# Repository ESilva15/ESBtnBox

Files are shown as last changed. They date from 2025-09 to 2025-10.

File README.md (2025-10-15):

# ESBtnBox
Simple button box for simracing and other activities. This works but its still
an early phase and I hope to subject it to a great list of improvements from
polishing the 3D models to making the whole thing more compact.

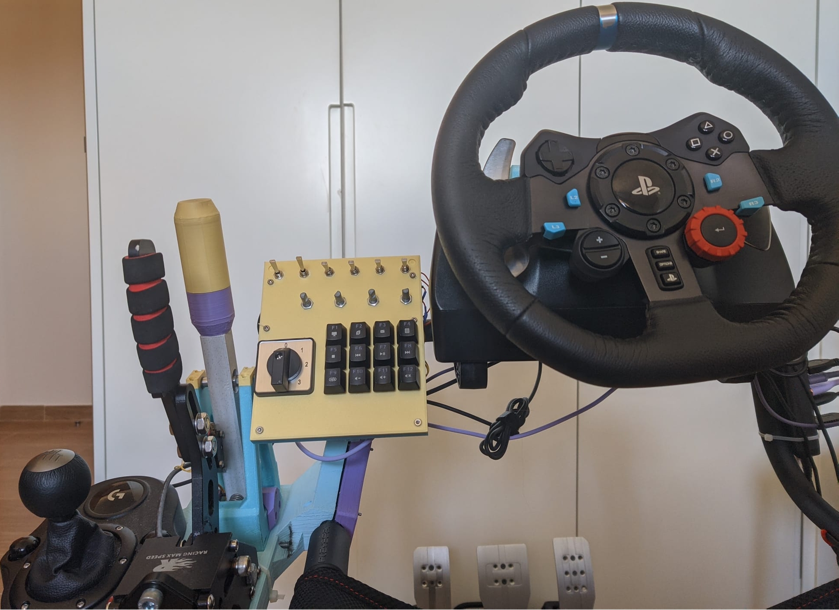
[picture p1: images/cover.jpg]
Project Overview


# Components
## Electronics
| Part | Quantity |
| --- | --- |
| Arduino Pro Micro (ATmega32u4) | 1 |
| Female Headers for pro micro | 24 |
| JST-PH Connectors (6 pin) male and female | 1 | [^1]
| JST-PH Connectors (5 pin) male and female | 1 |
| JST-PH Connectors (3 pin) male and female | 1 |
| JST-PH Connectors (2 pin) male and female | 3 |
| Perf boards 70mm x 500mm | 2 |
| 100nF Capacitors | 10 |
| 74HC595N Shift Register | 1 |
| 74HC165N Shift Register | 1 |
| 10k Ohm Resistors | 20 |
| 1N4148 diodes | 26 |
| Toggle Switches | 6 | [^2]
| Rotary Encoders | 4 |
| 2P LW26-25 series changeover switch | 1 |
| MX switches (and keycaps I recon) | 12 |
| Wiring and consumables | Lots |

[^1]: I used 2mm pitch for these connectors, but they didn't really match the
pitch of the perf board I was using. Choosing other pitches wouldn't be a bad
idea.

[^2]: I used 4 On-Off-On switches and 2 MOM-Off-MOM switches. Permutate it
however you desire.

## Hardware
| Part | Quantity |
| --- | --- |
| M3 nuts | 20 | [^3]
| M5 nuts | 2 |
| M3x40mm | 4 | [^4]
| M3x12mm | 2 |
| M3x50mm | 4 |
| M5x20mm | 2 |
| M3 t-nut | 2 |
| M2 Heat Inserts | 7 |
| M2x6mm | 7 |

[^3]: 4 of these are optional: the ones on the outwards facing piece that connects 
to the playseat and the 2 top ones on the front plate

[^4]: 2 of these are optional: the ones on the outwards facing piece that connects
to the playseat structure.

## 3D printed parts
- Clamp: composed by the files `./3DModel/seatAttachement_screwSide.FCStd` and
`./3DModel/seatAttachement.FCStd`, the latter is the the one facing the seating
user and the first the one facing outwards
- Arm which is the file `./3DModel/arm.FCStd`
- T-slot which bolts to the front plate: `./3DModel/tSlot.FCStd`
- T-slot bracket which bolts to the t-slot and the arm: `./3DModel/tSlotAttachement.FCStd`
- Front plate where all the buttons are mounted to: `./3DModel/frontPlate.FCStd`
- Cover plate which where the "pcb" mounts and connects to the front plate: `./3DModel/pcbHolder.FCStd`
- Very simple knob for the rotary encoders: `./3DModel/knob.FCStd`

# Assembly
The assembly is straightforward, specially if you are the one that imagined it:
1. put the toggle switches into their through holes and bolt them
2. put the rotary encoders into their through holes and bolt them
3. insert the MX switches into their holes
4. bolt the changeover switch into its slot
5. wire the things according to the schematic. I started by doing the columns
and then the rows and left the rotary part of the encoders for the end. Crimp
the JSH-PH connectors on the rows, columns and rotary encoders
6. solder the components to the perf boards. I joined the 2 perf boards like the
images show
7. mount the back cover
    1. put the heat inserts into the back cover
    2. bolt the perf boards to the back cover
    3. drill holes on the front plate for the back cover holes. They go 7.5mm
    in from the front plate edges, 1.5mm below the toggle switches and are spaced
    apart by 45mm
    4. pass the M3x50mm bolts trough the front plate and put nuts holding them
    5. place nuts 8mm down from the tip on them
    6. connect the front plate electronics to the pcb
    7. place the back cover on the M3x50mm bolts and put nuts on it
8. bolt the t-slot 3D printed part tot he front plate and pass the t-nuts into it
9. place the t-slot attachement on the t-nuts. Leave them loose for later adjustments
10. heat insert the M5 nuts into the arm and the M3 nuts on inside part of the clamp
11. loosely assemble the arm
12. place the assembly on the playseat and clamp it down with the M3x40mm bolts
13. do the final adjustments and tighten everything down

## Schematics
Well, I'm not very well versed on KiCAD or eletronics design in general, so all
I have is the following hand drawings and pinouts. I will make something better 
at some point.

### Shift registers:
| Pro Micro Pin | 74HC595N Pin |
| --- | --- |
| 4 | 14 |
| 5 | 12 |
| 6 | 11 |
| GND | 8 |
| GND | 13 |
| 5V | 16 |
| 5V | 10 |
Put a capacitor on the 5V and common Ground

| Pro Micro Pin | 74HC165N Pin |
| --- | --- |
| 7 | 15 |
| 8 | 7 |
| 9 | 2 |
| 10 | 1 |
| GND | 8 |
| GND | 13 |
| 5V | 16 |
Put a capacitor on the 5V and common Ground

#### Shift registers to kbd matrix
Rows on the 595N:
| 74HC595N Pin | Matrix Row |
| --- | --- |
| 1 | 5 |
| 2 | 4 |
| 3 | 3 |
| 4 | 2 |
| 5 | 1 |
| 6 | 0 |

Columns on the 165N:
| 74HC165N Pin | Matrix Col |
| --- | --- |
| 14 | 4 |
| 3 | 3 |
| 4 | 2 |
| 5 | 1 |
| 6 | 0 |

### Rotary Encoders
Referring to the rotary encoders from the front view.
Only the first one will have the common ground specified because thats the one
that runs the ground for all the others.

1st:
| Pro Micro Pin | Rotary Encoder Pin |
| --- | --- |
| 14 | Top |
| GND | Middle |
| 16 | Bottom |

2nd:
| Pro Micro Pin | Rotary Encoder Pin |
| --- | --- |
| 15 | Top |
| 18 | Bottom |

3rd:
| Pro Micro Pin | Rotary Encoder Pin |
| --- | --- |
| 19 | Top |
| 20 | Bottom |

4th:
| Pro Micro Pin | Rotary Encoder Pin |
| --- | --- |
| 3 | Top |
| 2 | Bottom |

### Visual Aid
Matrix Wiring:
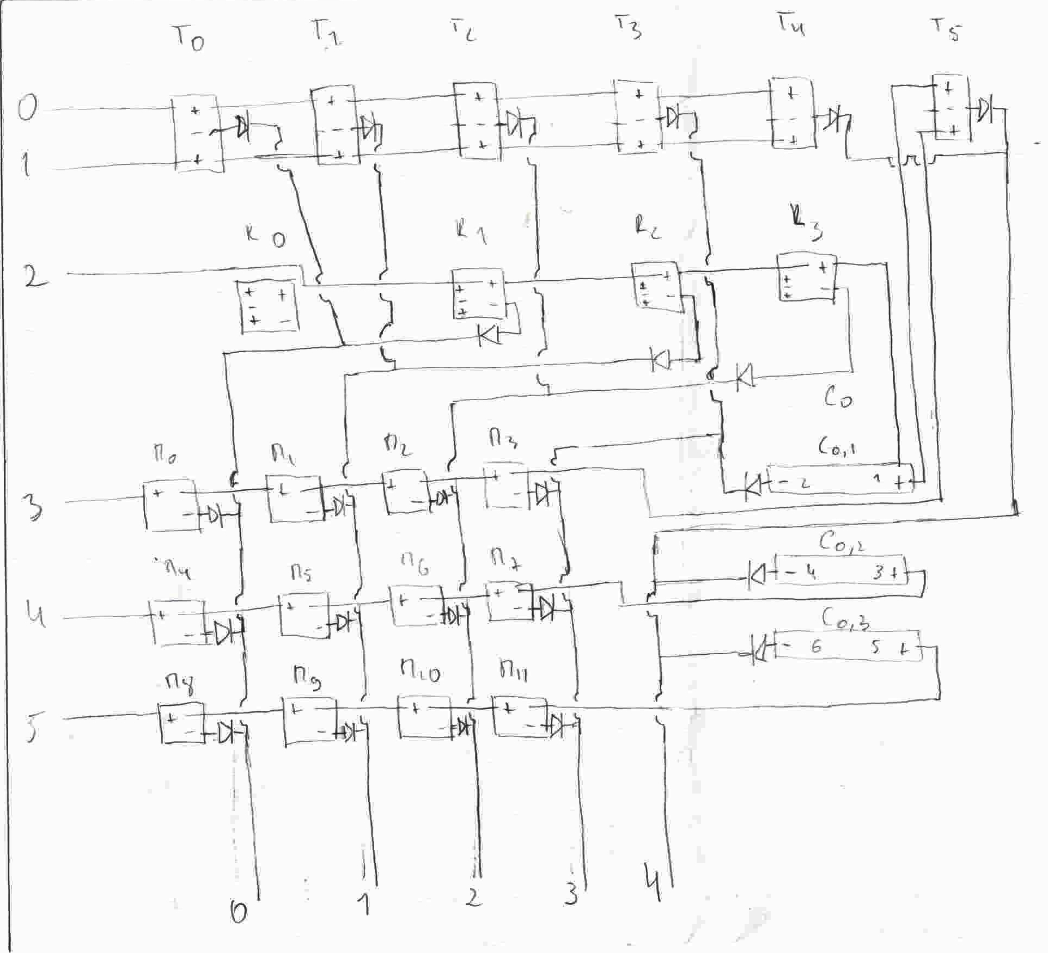
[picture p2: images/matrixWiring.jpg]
Matrix Wiring Schematic

    
2 Pin JST-PH connectors from the rotary encoder:
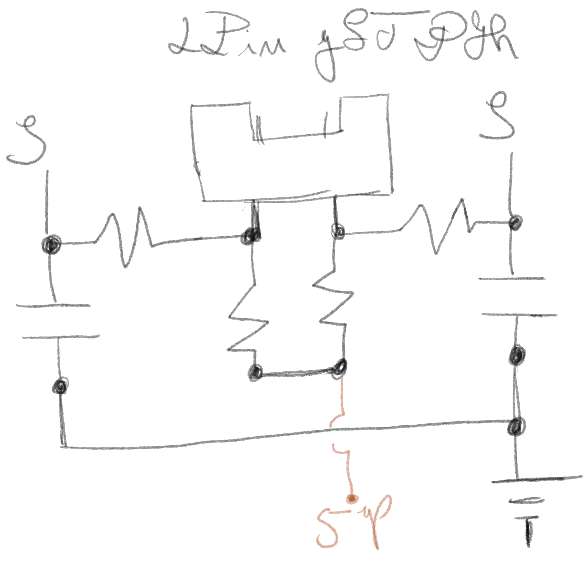
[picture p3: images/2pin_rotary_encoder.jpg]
2 Pin JST-PH connectors from the rotary encoder


3 Pin JST-PH connectors from the rotary encoder:
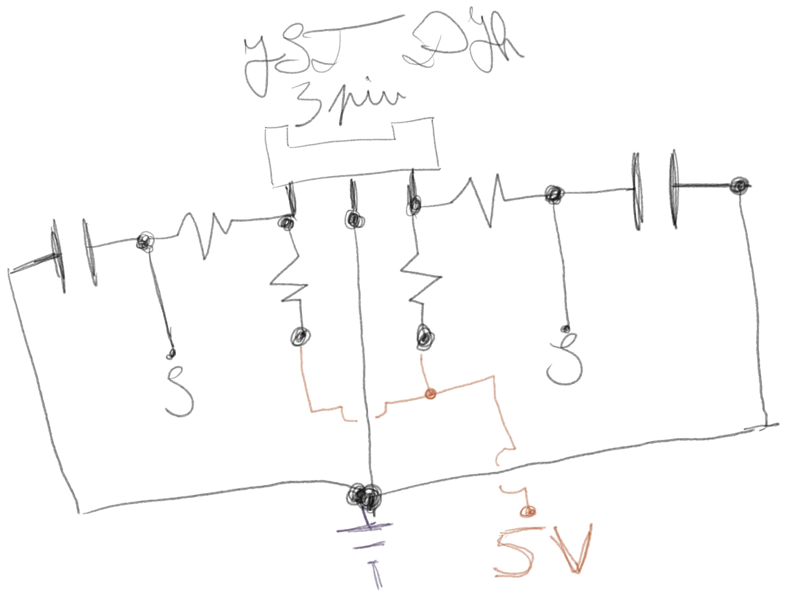
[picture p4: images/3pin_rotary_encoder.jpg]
3 Pin JST-PH connectors from the rotary encoder


## Assembled project
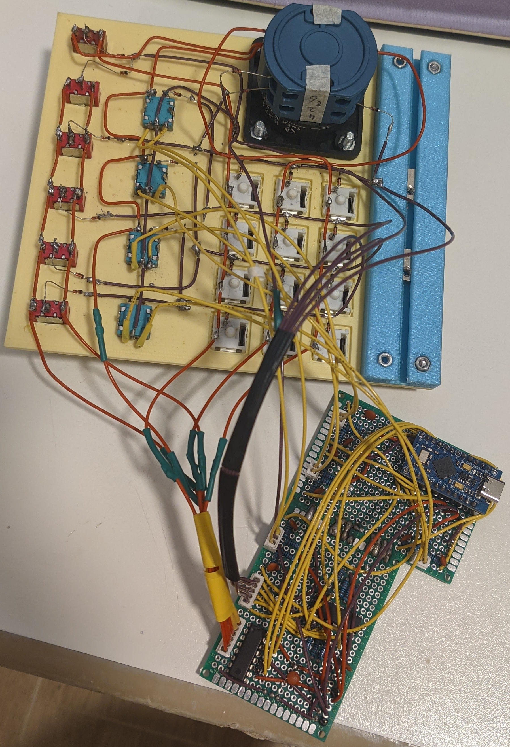
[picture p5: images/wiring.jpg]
Wiring

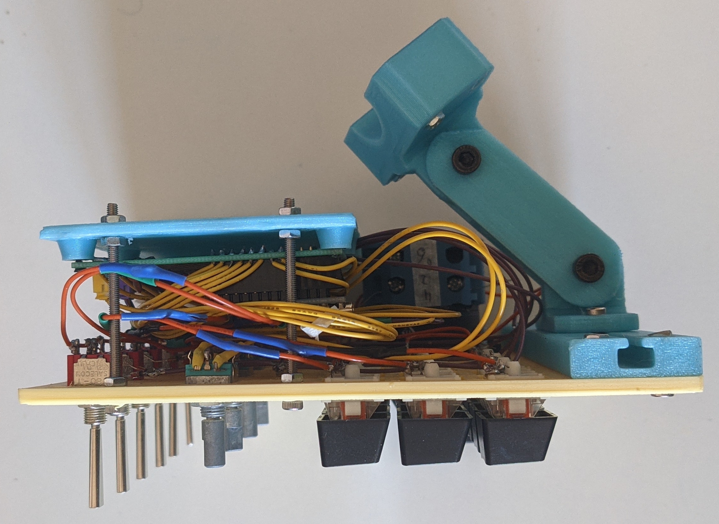
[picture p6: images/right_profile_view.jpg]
Right Profile View

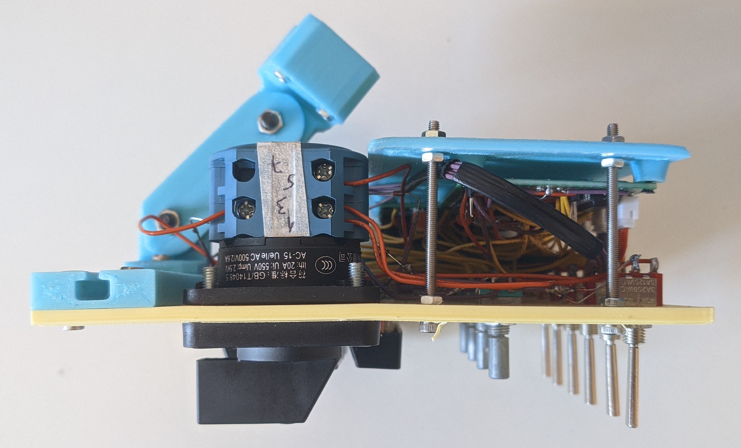
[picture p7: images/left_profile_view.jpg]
Left Profile View

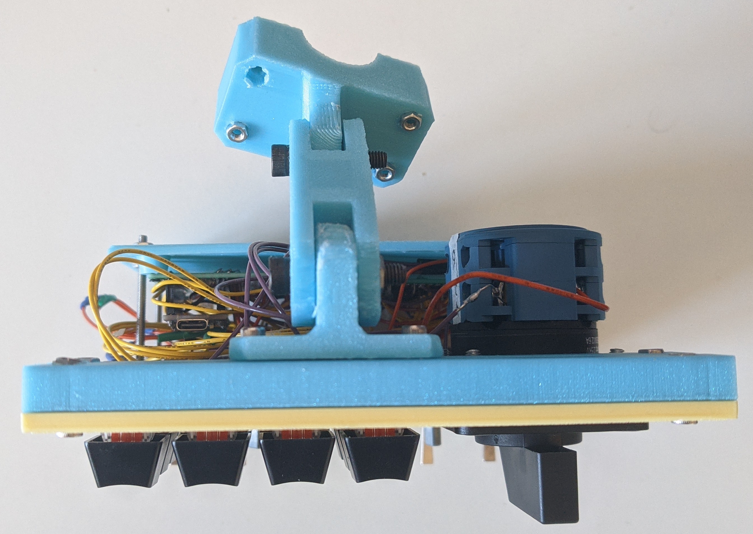
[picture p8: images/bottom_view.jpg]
Bottom View

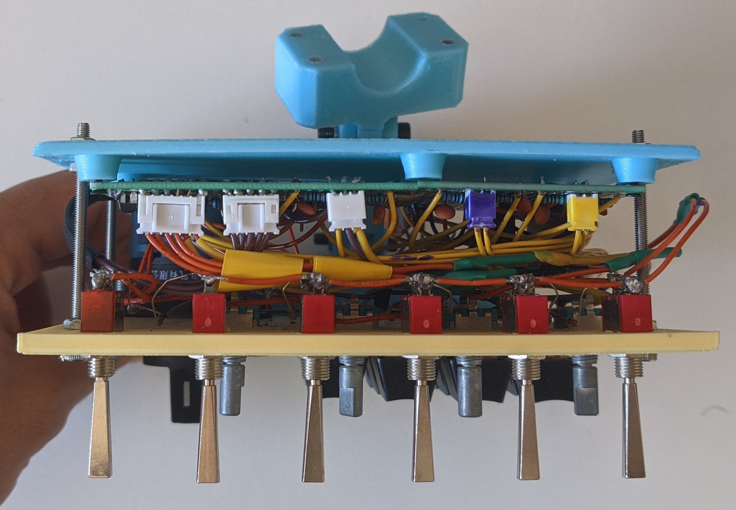
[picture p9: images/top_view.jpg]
Top View

Fully Assembled

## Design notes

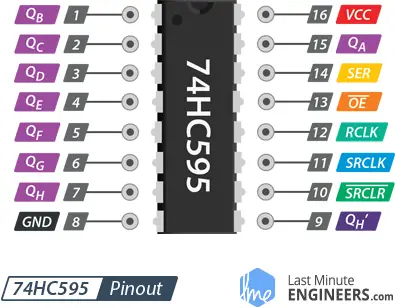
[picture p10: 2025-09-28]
images/595n_pinout.webp

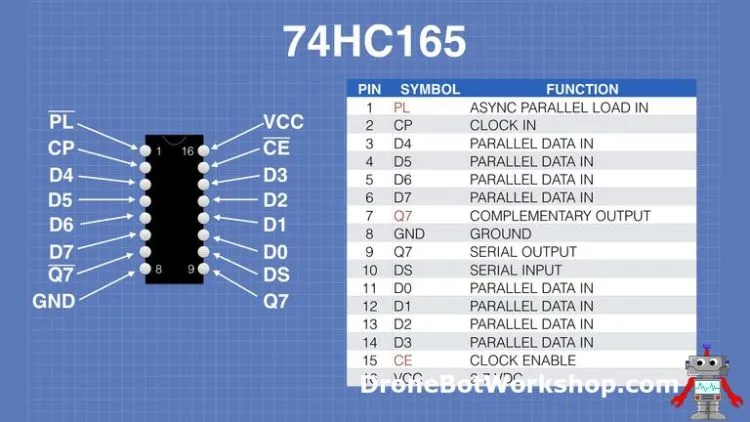
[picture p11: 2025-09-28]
images/165_pinout.webp

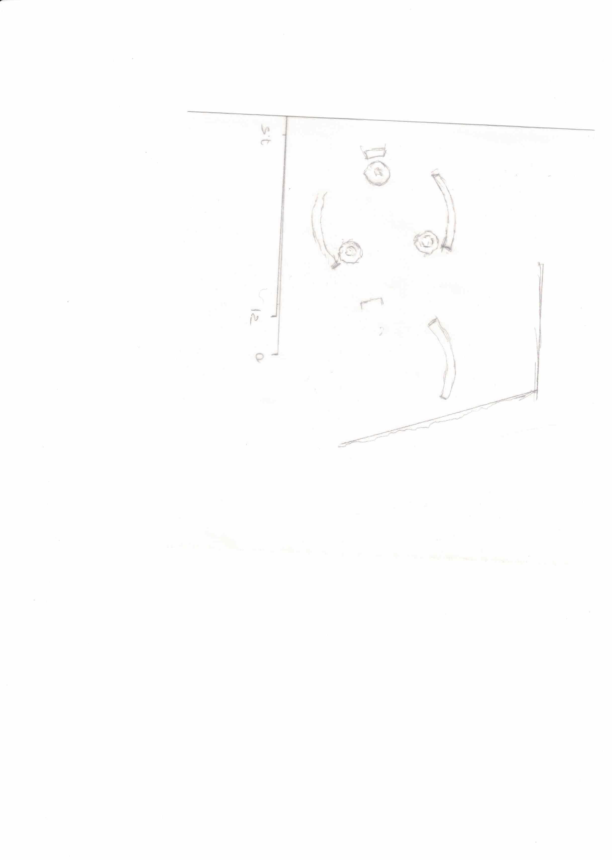
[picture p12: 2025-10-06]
3DModel/playseatBracketAngle.jpg

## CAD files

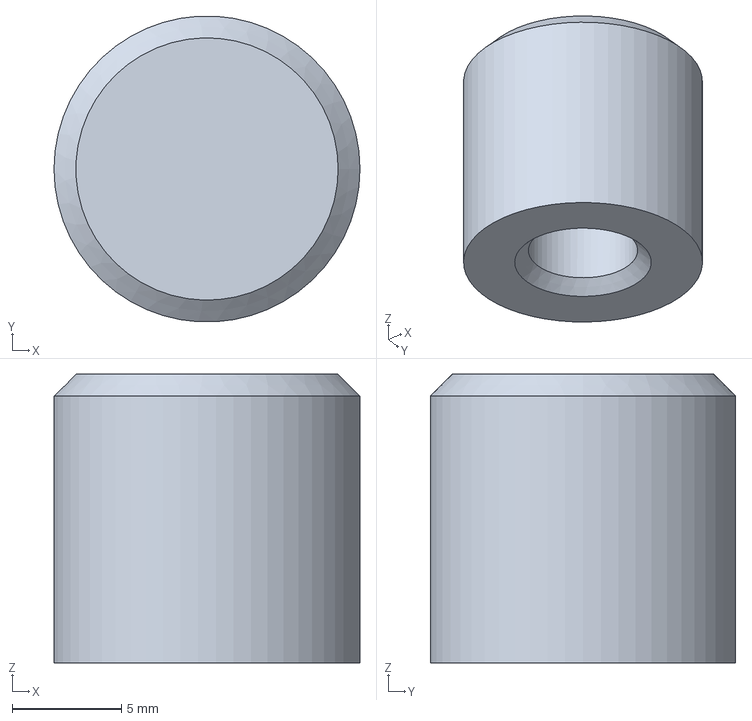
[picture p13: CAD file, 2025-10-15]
3DModel/knob.FCStd
14.0 x 14.0 x 13.2 mm

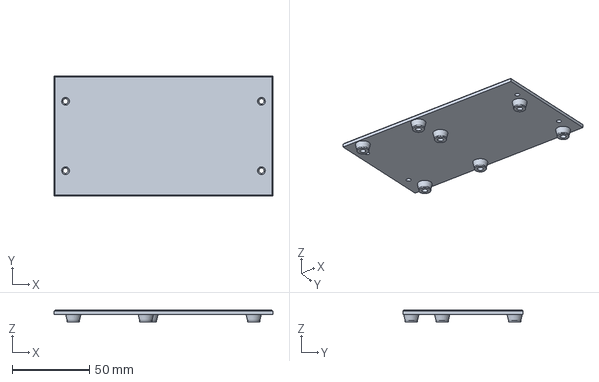
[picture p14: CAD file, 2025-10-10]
3DModel/pcbHolder.FCStd
142.0 x 78.0 x 8.00 mm

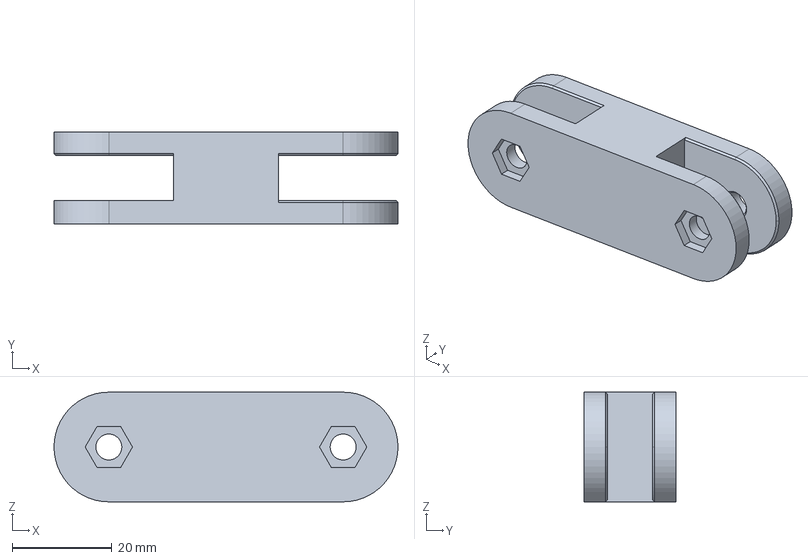
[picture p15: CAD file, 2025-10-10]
3DModel/extension.FCStd
69.0 x 18.4 x 22.0 mm

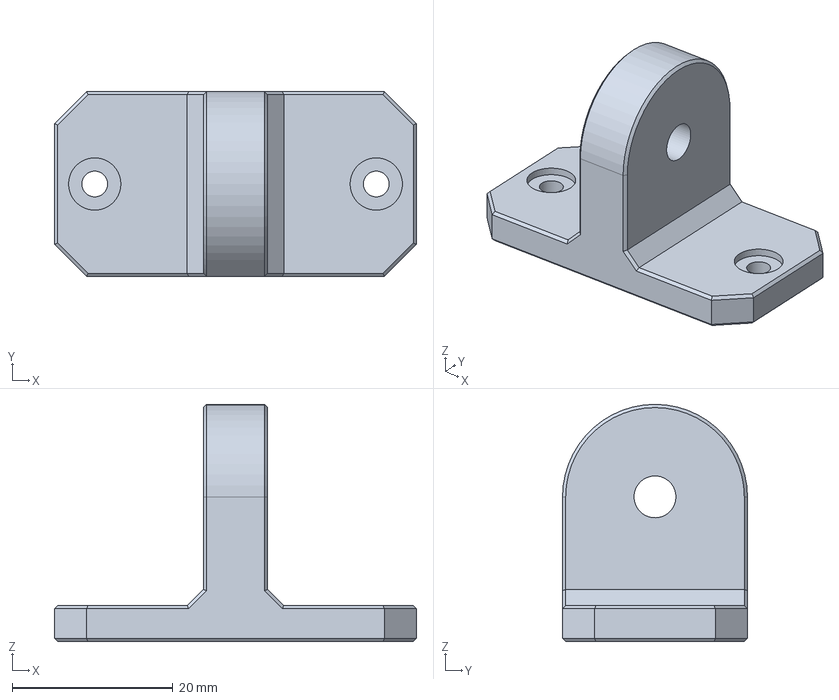
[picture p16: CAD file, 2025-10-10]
3DModel/tSlotAttachement.FCStd
45.0 x 23.0 x 29.5 mm

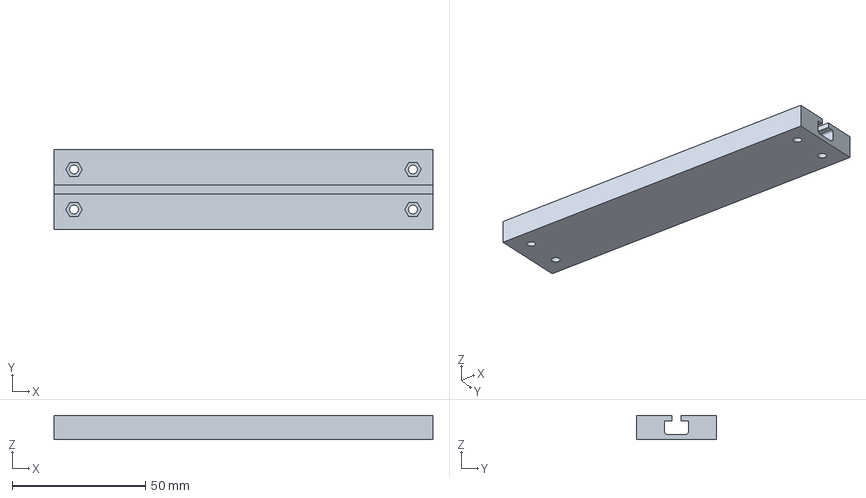
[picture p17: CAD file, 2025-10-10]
3DModel/tSlot.FCStd
142.0 x 30.0 x 9.00 mm

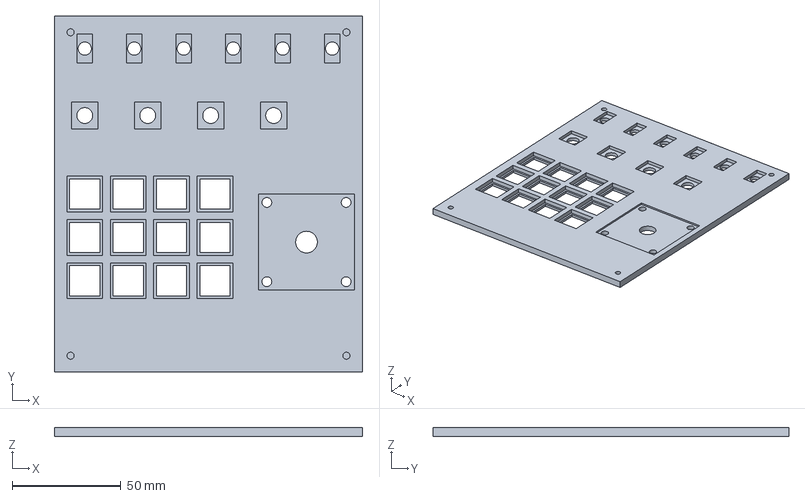
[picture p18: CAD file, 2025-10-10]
3DModel/frontPlate.FCStd
142.0 x 164.0 x 4.00 mm

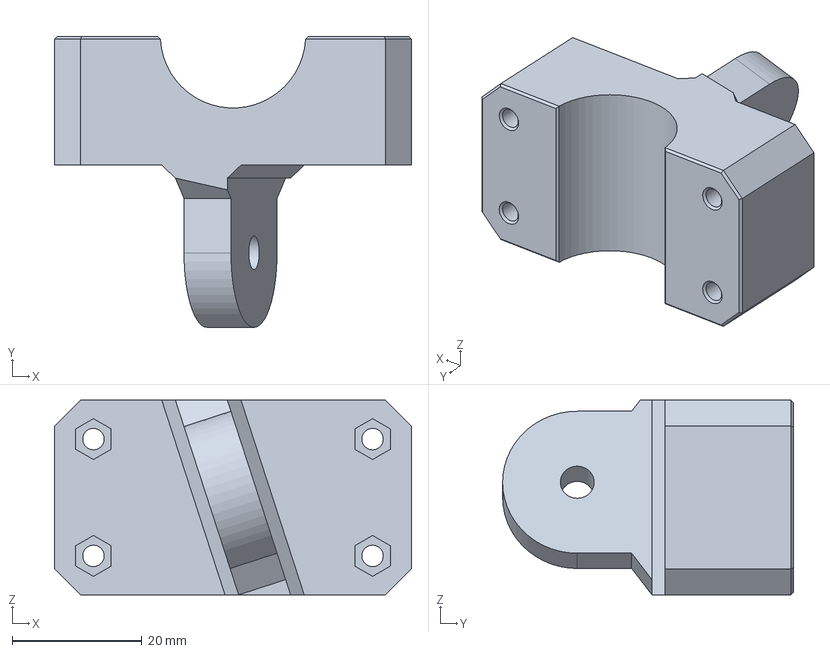
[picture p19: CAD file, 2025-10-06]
3DModel/seatAttachement.FCStd
55.0 x 44.8 x 30.0 mm

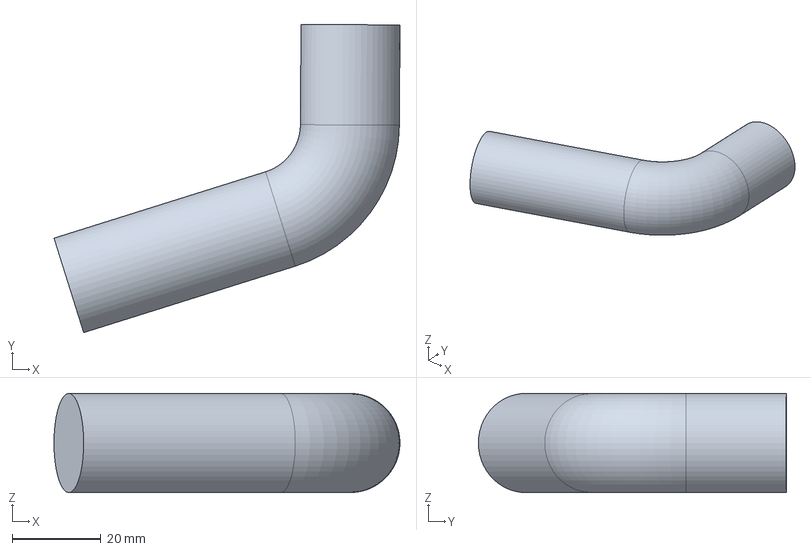
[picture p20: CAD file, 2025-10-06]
3DModel/arm.FCStd
78.0 x 69.5 x 22.3 mm

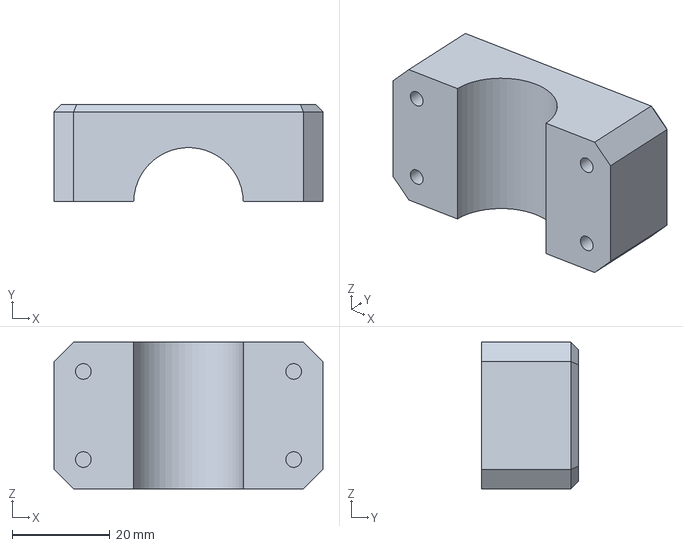
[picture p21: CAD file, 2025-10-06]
3DModel/seatAttachement_screwSide.FCStd
55.0 x 19.8 x 30.0 mm

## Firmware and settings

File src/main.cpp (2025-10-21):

/* BtnBOX by Eduardo Silva
 * Notes:
 * calling Wire.begin() will take use of the pins 2 and 3. Maybe try not using
 * them from the getgo
 */

// The Matrix
/* 
 * 1 1 1 R3 F9 F10 F11 F12
 * 1 1 1 R2 F5 F6  F7  F8
 * 1 1 1 M1 F1 F2  F3  F4
 * 1 1 1 m1 R1 r1  r2  r3
 * 1 1 1 M2 T3 T4  T5  T6
 * 1 1 1 m2 t3 t4  t5  t6
 *
 * Toggle Switches (On - Off - On):
 * T -> up, t -> down.
 * From left to right
 *
 * Toggle Switches (Hold On - Off - Hold On)
 * M -> up, m -> down
 * From left to right
 *
 * Puny Rotary Encoders Click:
 * R1 - 3
 * From left to right
 *
 * Chonky Rotary Encoder:
 * R0 - 3
 * Positions on the encoder
 *
 * F keys:
 * F1 - F12
 * Count them
 *
 */

#include <Arduino.h>
#include "595n.h"
#include "165.h"
#include "rotaryEncoder.h"
#include <Joystick.h>

// NOTES - 595N
// On the board, the first output pin on the SR595 is Qb
// Which means that our outputs go from 0b00000010 to 0b01111110
#define IN_SERIAL_PIN 4 // SER   - pin14 (Serial Pin)
#define IN_LATCH_PIN  5 // RCLK  - pin12 (Latch Pin)
#define IN_CLOCK_PIN  6 // SRCLK - pin11 (Clock Pin)
/*                      
+--             --+
|P0 P1 P2 P3 P4 P5|
+-----------------+
*/
#define IN_P0 0b01000000
#define IN_P1 0b00100000
#define IN_P2 0b00010000
#define IN_P3 0b00001000
#define IN_P4 0b00000100
#define IN_P5 0b00000010
uint8_t rows[] = {IN_P0, IN_P1, IN_P2, IN_P3, IN_P4, IN_P5};
const size_t NUM_ROWS = 6;

// NOTES - 165
#define OUT_PARALLEL_LOAD_IN  10 // PL - pin1  (Async Parallel Load In)
#define OUT_CLOCK_IN          9  // CP - pin2  (Clock In)
#define OUT_COMPLEMENTARY_OUT 8  // Q7 - pin7  (Complementary Output)
#define OUT_CLOCK_ENABLE      7  // CE - pin15 (Clock Enable)
/*
+--          --+
|P4 P3 P2 P1 P0|
+--------------+
*/
#define OUT_P0 0b11111110
#define OUT_P1 0b11111101
#define OUT_P2 0b11111011
#define OUT_P3 0b11110111
#define OUT_P4 0b11101111
uint8_t cols[] = {OUT_P0, OUT_P1, OUT_P2, OUT_P3, OUT_P4};
const size_t NUM_COLS = 5;

// Define the matrix state. Its all HIGH because of it being INPUT_PULLUP
// This is the matrix we will use to send the things to the JoyScick library
const unsigned long debounceDelay = 20;
uint8_t lastReading[NUM_ROWS][NUM_COLS] = {
  {HIGH, HIGH, HIGH, HIGH, HIGH},
  {HIGH, HIGH, HIGH, HIGH, HIGH},
  {HIGH, HIGH, HIGH, HIGH, HIGH},
  {HIGH, HIGH, HIGH, HIGH, HIGH},
  {HIGH, HIGH, HIGH, HIGH, HIGH},
  {HIGH, HIGH, HIGH, HIGH, HIGH},
};

uint8_t debouncedBtns[NUM_ROWS][NUM_COLS] = {
  {HIGH, HIGH, HIGH, HIGH, HIGH},
  {HIGH, HIGH, HIGH, HIGH, HIGH},
  {HIGH, HIGH, HIGH, HIGH, HIGH},
  {HIGH, HIGH, HIGH, HIGH, HIGH},
  {HIGH, HIGH, HIGH, HIGH, HIGH},
  {HIGH, HIGH, HIGH, HIGH, HIGH},
};

// This matrix we will use to debounce
unsigned long lastDebounceTime[NUM_ROWS][NUM_COLS] = {
  {0, 0, 0, 0, 0},
  {0, 0, 0, 0, 0},
  {0, 0, 0, 0, 0},
  {0, 0, 0, 0, 0},
  {0, 0, 0, 0, 0},
  {0, 0, 0, 0, 0},
};

// Scan Results to be used each loop
uint8_t results[NUM_ROWS] = {
  0b11111111,
  0b11111111,
  0b11111111,
  0b11111111,
  0b11111111,
  0b11111111,
};

// Colmasks
const uint8_t colMasks[NUM_COLS] = {
  0b00000001,
  0b00000010,
  0b00000100,
  0b00001000,
  0b00010000
};

SR595N input = NewSR595N(IN_SERIAL_PIN, IN_LATCH_PIN, IN_CLOCK_PIN);
SR165 output = NewSR165(OUT_PARALLEL_LOAD_IN, OUT_CLOCK_ENABLE, 
                        OUT_CLOCK_IN, OUT_COMPLEMENTARY_OUT);

#define JOYSTICK_MATRIX_BTN_COUNT 40
#define JOYSTICK_MATRIX_HAT_COUNT 0
#define JOYSTICK_RE_OFFSET 32
Joystick_ Joystick(
  JOYSTICK_DEFAULT_REPORT_ID,
  JOYSTICK_TYPE_JOYSTICK,
  JOYSTICK_MATRIX_BTN_COUNT, // Button count
  JOYSTICK_MATRIX_HAT_COUNT, // Hat switch count
  // no axes since this is just buttons
  false, false, false, false, false,
  false, false, false, false, false,
  false
);


RotaryEncoder re1 = NewRotaryEncoder(14, 16);
RotaryEncoder re2 = NewRotaryEncoder(15, 18);
// RE3 physically isn't working
// RotaryEncoder re3 = NewRotaryEncoder(19, 20);
RotaryEncoder re4 = NewRotaryEncoder(3, 2);
RotaryEncoder* encoders[] = {&re1, &re2, &re4};
const size_t ROTARY_ENCODER_COUNT = 3;

#define PULSE_DURATION 100 // ms

const int pulseButtons[] = {
  23, 28, 22, 27, 21, 26, 20, 25,
  18, 9, 4
};
const size_t NUM_PULSE_BTNS = sizeof(pulseButtons) / sizeof(pulseButtons[0]);
unsigned long pulseStartTime[JOYSTICK_MATRIX_BTN_COUNT] = {0};
bool isPulsing[JOYSTICK_MATRIX_BTN_COUNT] = {false};

bool isPulseButton(int idx) {
  for (size_t k = 0; k < NUM_PULSE_BTNS; k++) {
    if (pulseButtons[k] == idx) {
      return true;
    }
  }
  return false;
}

uint8_t joystickREPos(int8_t dir, size_t encPos) {
   uint8_t btn = 32 + (encPos * 2);
   if (dir == -1) {
     btn += 1;
   }

   return btn;
}

// TODO
// Make this non blocking:
// - Set it has high, and on the following loops check if the required duration
// has elapsed to release it
void rotateRE(int8_t pos) {
   Joystick.setButton(pos, HIGH);
   delay(RE_PULSE_DURATION);
   Joystick.setButton(pos, LOW);
}

void setup() {
  Serial.begin(115200);

  Joystick.begin();
  for(int k = 0; k < JOYSTICK_MATRIX_BTN_COUNT; k++) {
    Joystick.setButton(k, 0);
  }

  SR595N_write(&input, 0b00000100);

  for (size_t k = 0; k < ROTARY_ENCODER_COUNT; k++) {
    RotaryEncoder_init(encoders[k]);
  }
}

// TODO - comment this debugging thing at the end
// unsigned long lastPrint = 0;
void loop(void) {
  unsigned long currentMillis = millis();

  for (size_t k = 0; k < ROTARY_ENCODER_COUNT; k++) {
    int dir = RotaryEncoder_read(encoders[k]);

    if (dir != LOW) {
      uint8_t btn = joystickREPos(dir, k);
      rotateRE(btn);
    }
  }

  for (size_t r = 0; r < NUM_ROWS; r++) {
    SR595N_write(&input, rows[r]);
    byte result = SR165_read(&output);

    for (size_t c = 0; c < NUM_COLS; c++) {
      uint8_t reading = (result & colMasks[c]) ? HIGH : LOW;
      int buttonIndex = r * NUM_COLS + c;

      // Debounce handling
      if (reading != lastReading[r][c]) {
        lastDebounceTime[r][c] = currentMillis;
      }

      if ((currentMillis - lastDebounceTime[r][c]) > debounceDelay) {
        if (reading != debouncedBtns[r][c]) {
          debouncedBtns[r][c] = reading;

          if (isPulseButton(buttonIndex)) {
            // Pulse on *any* change (ON or OFF)
            Joystick.setButton(buttonIndex, HIGH);
            pulseStartTime[buttonIndex] = currentMillis;
            isPulsing[buttonIndex] = true;
          } else {
            // Normal button logic
            Joystick.setButton(buttonIndex, (reading == LOW));
          }
        }
      }

      lastReading[r][c] = reading;
    }
  }

  // End pulses after duration
  for (int i = 0; i < JOYSTICK_MATRIX_BTN_COUNT; i++) {
    if (isPulsing[i] && (currentMillis - pulseStartTime[i]) > PULSE_DURATION) {
      Joystick.setButton(i, 0);
      isPulsing[i] = false;
    }
  }

  // if (millis() - lastPrint >= 50) {
  //   Serial.print("\033[2J\033[H");
  //   for (size_t row = 0; row < NUM_ROWS; row++) {
  //     for (size_t col = 0; col < NUM_COLS; col++) {
  //       Serial.print(debouncedBtns[row][col] == LOW ? "X " : ". ");
  //     }
  //     Serial.println();
  //   }
  //   Serial.println();
  //
  //   for (size_t row = 0; row < NUM_ROWS; row++) {
  //     Serial.println(results[row], BIN);
  //   }
  //
  //   lastPrint = millis();
  // }
}

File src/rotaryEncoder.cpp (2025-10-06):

#include "rotaryEncoder.h"
#include "Arduino.h"

RotaryEncoder NewRotaryEncoder(int clk, int dt) {
  return RotaryEncoder{
    .clkPin = clk,
    .dtPin = dt,
  };
}

void RotaryEncoder_init(RotaryEncoder *enc) {
  pinMode(enc->clkPin, INPUT_PULLUP);
  pinMode(enc->dtPin, INPUT_PULLUP);
  enc->lastStateCLK = digitalRead(enc->clkPin);
}

int RotaryEncoder_read(RotaryEncoder *enc) {
  int curStateClk = digitalRead(enc->clkPin);
  int direction = RE_NOCHANGE;
  
  if (curStateClk != enc->lastStateCLK && curStateClk == 1) {
    if (digitalRead(enc->dtPin) != curStateClk) {
      direction = RE_CCW; 
    } else {
      direction = RE_CW; 
    }
  }

  enc->lastStateCLK = curStateClk;

  return direction;
}

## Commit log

2025-10-06 3DModels for priting and attaching the the playseat challenge
    fits to the left of the wheel base
    [arm.FCStd, extension.FCStd, frontPlate.FCStd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]
2025-10-06 Changed the behaviour of the toggle switches (now they behave like keys)
2025-10-06 Started adding the rotary encoder
    If only soldering could be a commit...
2025-10-08 Added the rotary encoders as buttons (one of them is broken, so I will fix the code later)
    [main.cpp]
2025-10-10 Modified some parameters on the current models like shortening the arm
    [extension.FCStd, frontPlate.FCStd, tSlot.FCStd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]
2025-10-10 Added a plate to hold the <quote>pcb</quote>
    [pcbHolder.FCStd]
2025-10-15 Added a simple part to be the knob of the rotary encoders
    [knob.FCStd]
2025-10-21 Changed the press duration for the rotary encoder in hopes games detect it btr
